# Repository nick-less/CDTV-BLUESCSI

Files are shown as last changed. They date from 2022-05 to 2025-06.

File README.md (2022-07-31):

A Version of the CDTV SCSI Card with an added bluepill SCSI Emulator

Works with https://github.com/erichelgeson/BlueSCSI

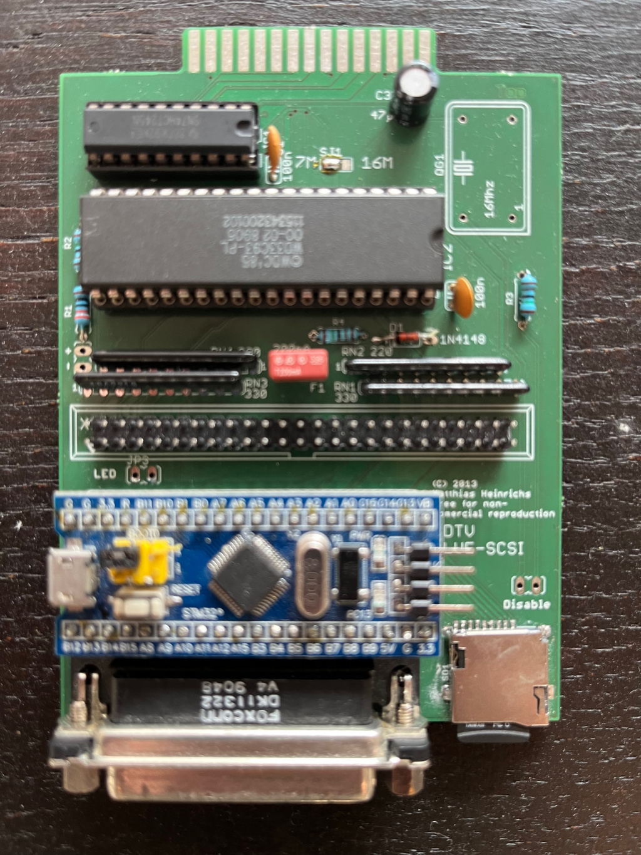
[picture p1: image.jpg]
 

```
Partlist

Part     Value          Package      Library      Position (mil)        Orientation

C1       100n           C025-024X044 rcl          (1318 3336)           R90
C2       100n           C025-024X044 rcl          (2406 2573)           R90
C3       47µ            E2,5-6E      rcl          (2144 3728)           R0
CN1      CDTV-EXPANSION CDTV-SLOT    Amiga        (1535 3964)           R180
D1       1N4148         DO35-7       diode        (2118 2309)           R0
F1       200mA          TE5          fuse         (1472 2144)           R180
IC1      74HC245N       DIL20        74xx-eu      (742 3468)            R180
IC2      WD33C93A       DIP40-6      Amiga        (1274 2824)           R180
JP1                     JP1          jumper       (160 2192)            R180
JP2                     JP1          jumper       (2868 814)            R270
JP3                     JP1          jumper       (528 1488)            R270
QG1      16Mhz          DIL14S       crystal      (2617 3349)           R90
R1       330            0207/7       rcl          (164 2475)            R270
R2       1k             0207/7       rcl          (164 2846)            R90
R3       1k             0207/7       rcl          (2827 2549)           R270
R4       1k             0207/7       rcl          (1712 2336)           R0
RN1      330            SIL10        resistor-sil (2338 2019)           R180
RN2      220            SIL10        resistor-sil (2238 2149)           R0
RN3      330            SIL10        resistor-sil (638 2019)            R0
RN4      220            SIL10        resistor-sil (738 2148)            R180
SD1      TF-HOLDER      TF-PULL      sd-mmc       (2688 272)            R180
SJ1                     SJ_2         jumper       (1697 3367)           R0
U$1                     BLUE_PILL    BluePill     (864 992)             R90
X1       057-050-1      057-050-1    con-panduit  (1488 1746)           R0
X2                      F25H         SparkFun     (1152 304)            R180
```

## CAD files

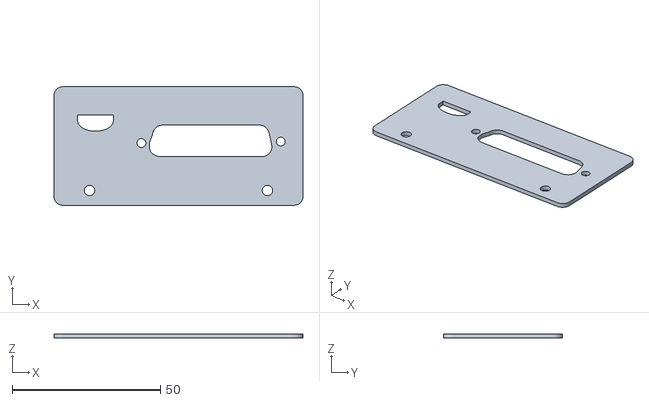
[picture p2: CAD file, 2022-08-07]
backpanel.stl
84.0 x 40.0 x 1.50

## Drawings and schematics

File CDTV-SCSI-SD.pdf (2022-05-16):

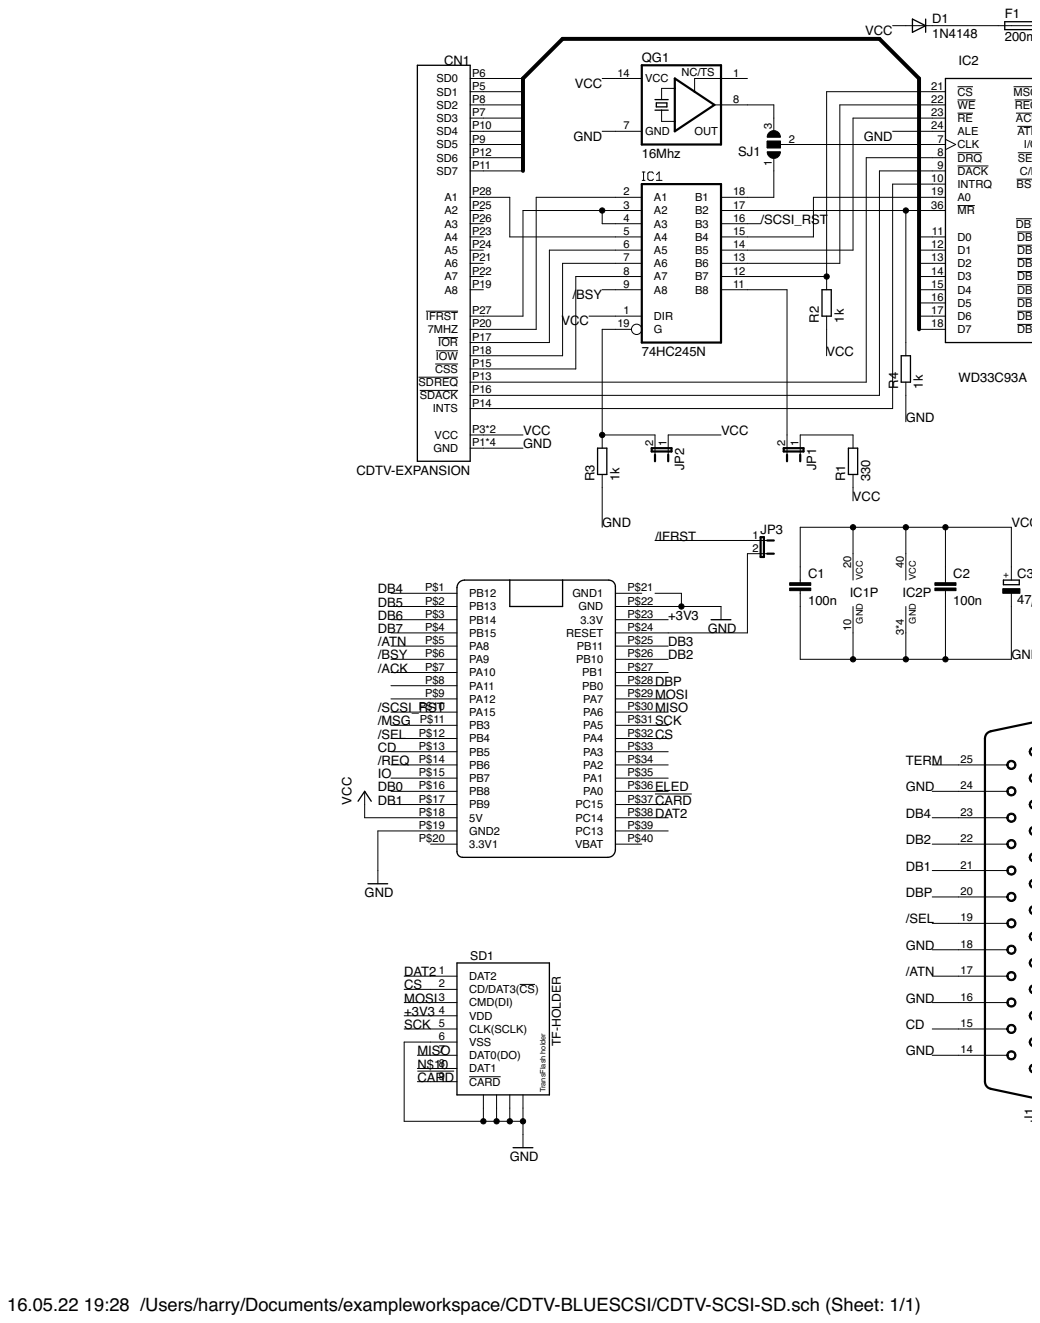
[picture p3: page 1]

16.05.22 19:28 /Users/harry/Documents/exampleworkspace/CDTV-BLUESCSI/CDTV-SCSI-SD.sch (Sheet: 1/1)

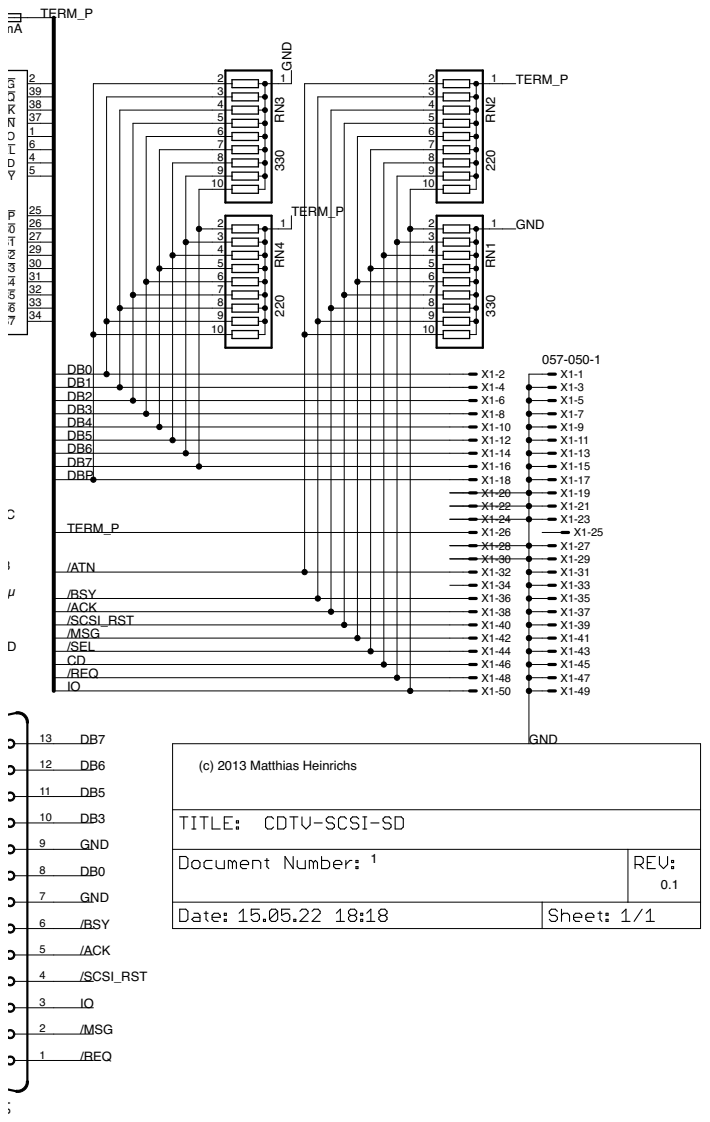
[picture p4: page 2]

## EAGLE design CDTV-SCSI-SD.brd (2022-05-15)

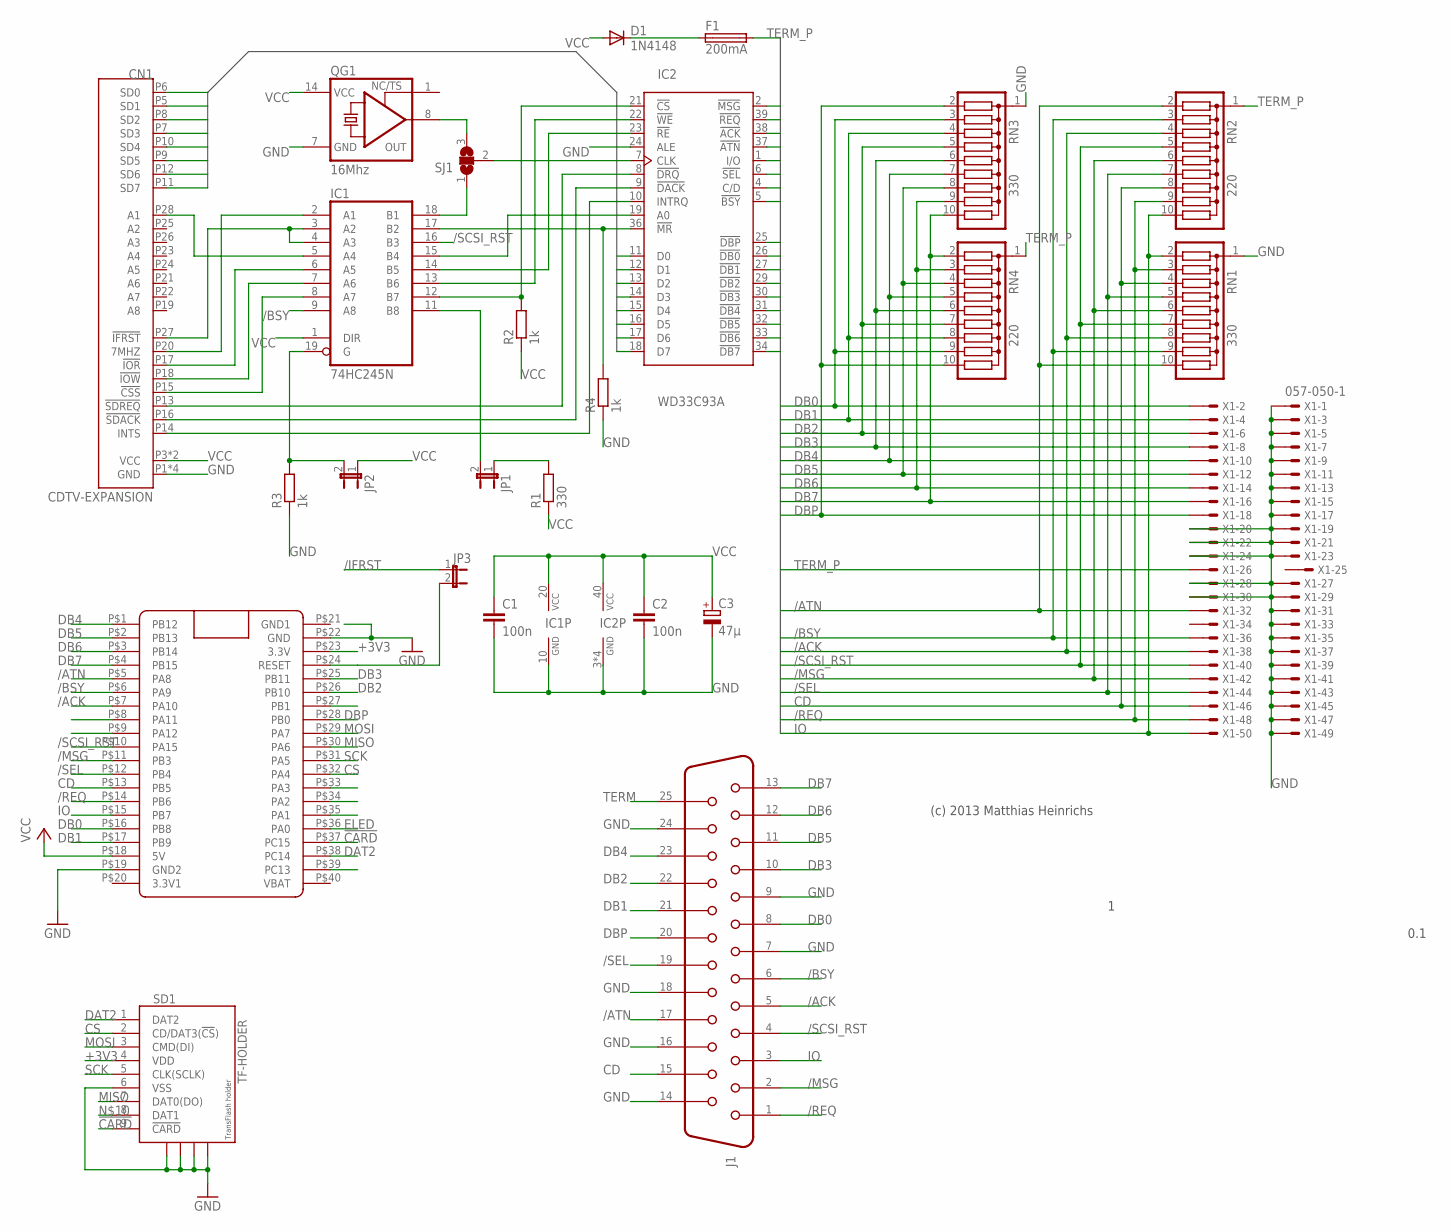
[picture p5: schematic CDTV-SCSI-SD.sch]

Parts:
C1, C2: 100n; C025-024X044
C3: 47µ; E2,5-6E
CN1: CDTV-EXPANSION; CDTV-SLOT
D1: 1N4148; DO35-7
F1: 200mA; TE5
IC1: 74HC245N; DIL20
IC2: WD33C93A; DIP40-6
J1: 61802529321
JP1, JP2, JP3: JP1E; JP1
QG1: 16Mhz; DIL14S
R1: 330; 0207/7
R2, R3, R4: 1k; 0207/7
RN1, RN3: 330; SIL10
RN2, RN4: 220; SIL10
SD1: TF-HOLDER; TF-PULL
SJ1: SJ2W; SJ_2
U$1: BLUE_PILL
X1: 057-050-1

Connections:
7MHZ: CN1.P20 (7MHZ), IC1.2 (A1)
!CARD: SD1.9 (!CARD), U$1.P$37 (PC15)
+3V3: SD1.4 (VDD), U$1.P$23 (3.3V)
/ACK: IC2.38 (!ACK), J1.5, RN1.8, RN2.4, U$1.P$7 (PA10), X1.38
/ATN: IC2.37 (!ATN), J1.17, RN1.10, RN2.2, U$1.P$5 (PA8), X1.32
/BSY: IC1.9 (A8), IC2.5 (!BSY), J1.6, RN1.9, RN2.3, U$1.P$6 (PA9), X1.36
/BSY_B: IC1.11 (B8), JP1.2
/CS: IC1.12 (B7), IC2.21 (!CS), R2.2
/CSS: CN1.P15 (!CSS), IC1.8 (A7)
/ENABLE: IC1.19 (G), JP2.2, R3.2
/IFRST: CN1.P27 (!IFRST), IC1.3 (A2), IC1.4 (A3), JP3.1
/INTS: CN1.P14 (INTS), IC2.10 (INTRQ)
/IOR: CN1.P17 (!IOR), IC1.6 (A5)
/IOW: CN1.P18 (!IOW), IC1.7 (A6)
/MR: IC1.17 (B2), IC2.36 (!MR), R4.2
/MSG: IC2.2 (!MSG), J1.2, RN1.6, RN2.6, U$1.P$11 (PB3), X1.42
/RE: IC1.14 (B5), IC2.23 (!RE)
/REQ: IC2.39 (!REQ), J1.1, RN1.3, RN2.9, U$1.P$14 (PB6), X1.48
/SCSI_RST: IC1.16 (B3), J1.4, RN1.7, RN2.5, U$1.P$10 (PA15), X1.40
/SDACK: CN1.P16 (!SDACK), IC2.9 (!DACK)
/SDREQ: CN1.P13 (!SDREQ), IC2.8 (!DRQ)
/SEL: IC2.6 (!SEL), J1.19, RN1.5, RN2.7, U$1.P$12 (PB4), X1.44
/WE: IC1.13 (B6), IC2.22 (!WE)
A1: CN1.P28 (A1), IC1.5 (A4)
B_A1: IC1.15 (B4), IC2.19 (A0)
CD: IC2.4 (C/D), J1.15, RN1.4, RN2.8, U$1.P$13 (PB5), X1.46
CLK: IC2.7 (CLK), SJ1.2
CLK_7: IC1.18 (B1), SJ1.1
CLK_16M: QG1.8 (OUT), SJ1.3
CS: SD1.2 (CD/DAT3(!CS!)), U$1.P$32 (PA4)
DAT2: SD1.1 (DAT2), U$1.P$38 (PC14)
DB0: IC2.26 (!DB0), J1.8, RN3.3, RN4.9, U$1.P$16 (PB8), X1.2
DB1: IC2.27 (!DB1), J1.21, RN3.4, RN4.8, U$1.P$17 (PB9), X1.4
DB2: IC2.29 (!DB2), J1.22, RN3.5, RN4.7, U$1.P$26 (PB10), X1.6
DB3: IC2.30 (!DB3), J1.10, RN3.6, RN4.6, U$1.P$25 (PB11), X1.8
DB4: IC2.31 (!DB4), J1.23, RN3.7, RN4.5, U$1.P$1 (PB12), X1.10
DB5: IC2.32 (!DB5), J1.11, RN3.8, RN4.4, U$1.P$2 (PB13), X1.12
DB6: IC2.33 (!DB6), J1.12, RN3.9, RN4.3, U$1.P$3 (PB14), X1.14
DB7: IC2.34 (!DB7), J1.13, RN3.10, RN4.2, U$1.P$4 (PB15), X1.16
DBP: IC2.25 (!DBP), J1.20, RN3.2, RN4.10, U$1.P$28 (PB0), X1.18
ELED: U$1.P$36 (PA0)
GND: C1.2, C2.2, C3.-, CN1.P1 (GND), CN1.P2 (GND), CN1.P29 (GND), CN1.P30 (GND), IC1.10 (GND), IC2.3 (GND1), IC2.20 (GND1), IC2.24 (ALE), IC2.28 (GND1), IC2.35 (GND1), J1.7, J1.9, J1.14, J1.16, J1.18, J1.24, QG1.7 (GND), R3.1, R4.1, RN1.1, RN3.1, SD1.6 (VSS), SD1.S1, SD1.S2, SD1.S3, SD1.S4, U$1.P$19 (GND2), U$1.P$22 (GND), X1.1, X1.3, X1.5, X1.7, X1.9, X1.11, X1.13, X1.15, X1.17, X1.19, X1.20, X1.21, X1.22, X1.23, X1.24, X1.27, X1.28, X1.29, X1.30, X1.31, X1.33, X1.35, X1.37, X1.39, X1.41, X1.43, X1.45, X1.47, X1.49
GND1: U$1.P$21 (GND1)
IO: IC2.1 (I/O), J1.3, RN1.2, RN2.10, U$1.P$15 (PB7), X1.50
LED_POW: JP1.1, R1.2
MISO: SD1.7 (DAT0(DO)), U$1.P$30 (PA6)
MOSI: SD1.3 (CMD(DI)), U$1.P$29 (PA7)
unnamed: JP3.2, U$1.P$24 (RESET)
SCK: SD1.5 (CLK(SCLK)), U$1.P$31 (PA5)
SD0: CN1.P6 (SD0), IC2.11 (D0)
SD1: CN1.P5 (SD1), IC2.12 (D1)
SD2: CN1.P8 (SD2), IC2.13 (D2)
SD3: CN1.P7 (SD3), IC2.14 (D3)
SD4: CN1.P10 (SD4), IC2.15 (D4)
SD5: CN1.P9 (SD5), IC2.16 (D5)
SD6: CN1.P12 (SD6), IC2.17 (D6)
SD7: CN1.P11 (SD7), IC2.18 (D7)
TERM: J1.25
TERM_P: F1.2, RN2.1, RN4.1, X1.26
TP_UNFUSED: D1.C, F1.1
VCC: C1.1, C2.1, C3.+, CN1.P3 (VCC), CN1.P4 (VCC), D1.A, IC1.1 (DIR), IC1.20 (VCC), IC2.40 (VCC1), JP2.1, QG1.14 (VCC), R1.1, R2.1, U$1.P$18 (5V)

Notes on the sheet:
0.1
(c) 2013 Matthias Heinrichs

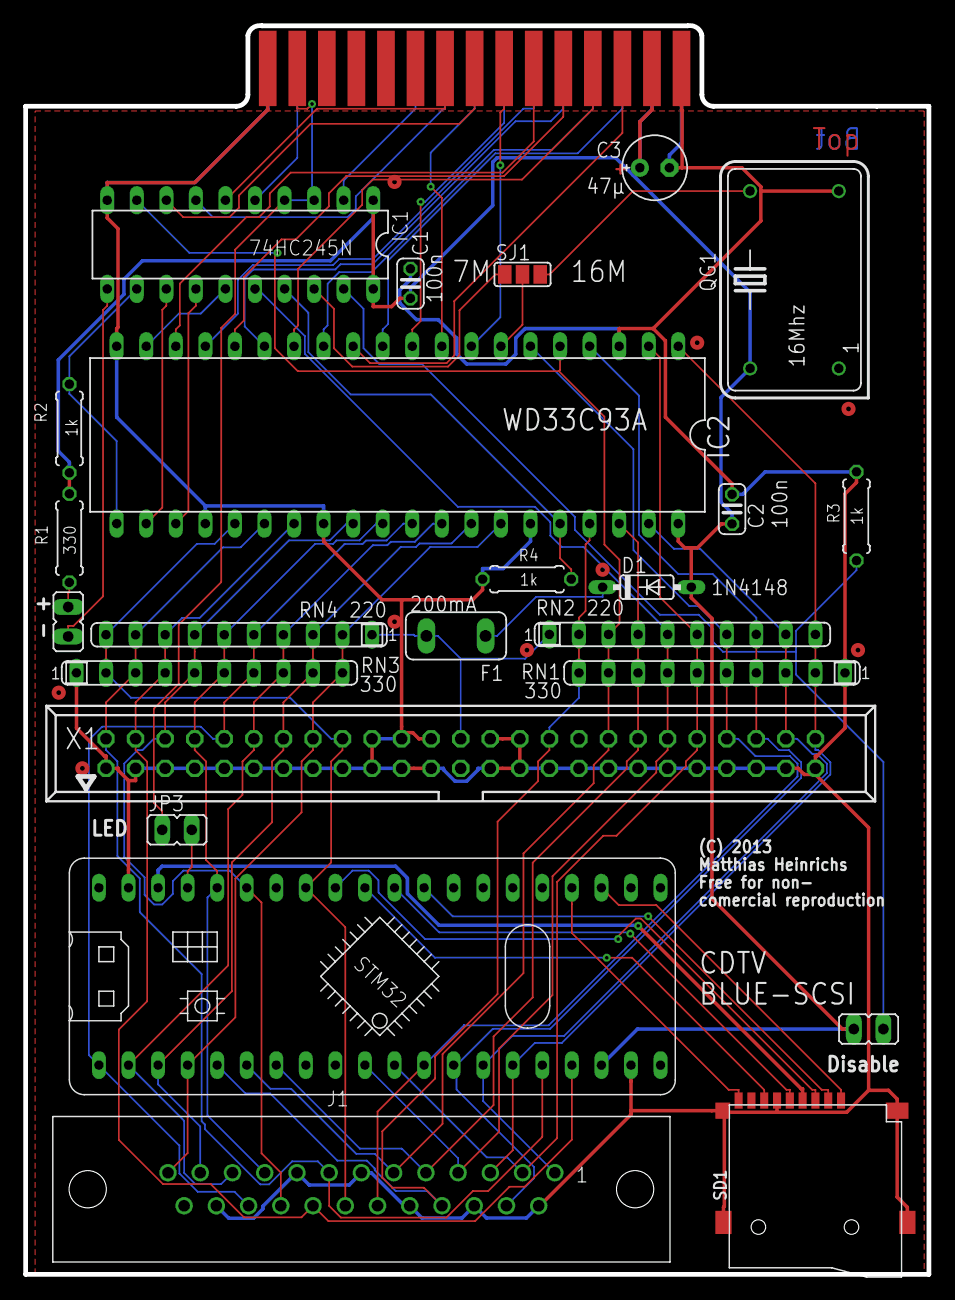
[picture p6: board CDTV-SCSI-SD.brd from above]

Board: 2 copper layers, 77.6 x 107.3 mm, 25 parts (0 on the bottom side), 58 nets.

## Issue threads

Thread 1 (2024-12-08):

Function of the JP3 jumper

LejonD, 2024-12-08:
Hello Nick,

Question what is the function of the JP3 jumper?
The JP2 is for disable/enable
The JP1 is for the LED.

So could you explain.

Lejon

nick-less, 2024-12-10:
JP3 connects /IFRST, which is the buffered /RESET signal from the CDTV to the STM32 reset input. Closing it will reset the STM32 whenever the Amiga is reset.

LejonD, 2024-12-10:
Could you also tell fot the TF-Holder, the card detect is it a open signal when (Micro)SD card is in or a closed signal when (Micro) SD card is in. Closed line is pulled to ground, or line open.
Lejon

nick-less, 2024-12-11:
Well, on my prototype inserting the card pulls it to ground, with no card its floating. Given that, you need to activate the builtin pullups on the stm32. I assume BiueSCSI does exactly that, because it worked out of the box with the prototype.

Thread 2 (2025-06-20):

Image issue?

Piemmeweb, 2025-06-20:
Hi, I built one of it for my CDTV (with dual kickstart 1.3 + 3.1) but it doesn't works. I don't know if it is an image issue or a card problem.
I assembled it totally and not as in the pic of the github page, also I seen on that pic you set up the internal 7 Mhz clock when it should be 16Mhz for the WD33C93A (7Mhz should be for the AM33C93A).
Also I don't know if the CDTV requires a scsi termination even if I didn't found a term jumper on the card.
Please can you tell me how to build the card correctly?
Also , I made an image called HD00_512.hda, in first with dd command, and after installing the workbench 3.1 inside using winuae.  But it doesn't boot, so I did a mistake... where I'm wrong? Can you tell me please how to build a working image? thanks in advance

nick-less, 2025-06-20:
Hi, first I updated the picture to reflect the working prototype. The one in the picture still shows MOSI and MISO flipped, so it’s not exactly the same as the version in this repository.

The 7 MHz clock for the WD33C93A always worked for me, so I never changed it. I had all the parts, except the termination resistors, laying around and didn’t want to wait to put it together. When I later ordered the termination resistors—which are totally needed—I also ordered a clock crystal but never bothered to install it. Technically, you would need termination on both sides, but since the length of the SCSI bus is very short, my version works with only the WD33C93A side terminated. However, adding a second set of termination might improve stability. If you’re cautious about termination, you can add an external terminator using the DB25 connector.

For the disk image, “HD00_512.hda” is okay (disk0, lun0, 512-byte blocks). Did you use HDToolbox to prepare it? Did you try it in UAE? Does it boot in UAE with the same Kickstart version?

Is the SD card formatted using FAT32 or ExtFS? NTFS usually doesn’t work. It’s also probably better to start with an image smaller than 2 GB. There are ways to use bigger images, but for a first test, keep it below 2 GB.

Does the device show up in autoconfig?

What does the LOG.txt on the SD card tell you? When you build the Bluescsi image, you can enable logging, which will write some information to the card, something like:

BlueSCSI <-> SD - https://github.com/erichelgeson/BlueSCSI
VERSION: 1.1-SNAPSHOT-20220627
DEBUG:0 SDFAT_FILE_TYPE:3
SdFat version: 2.0.6
Sd Format: exFAT
SPI speed: 50Mhz
SdFat Max FileName Length: 32
Initialized SD Card - lets go!
Sd MID:9F OID:TI
Sd Name:SD16G
Sd Date:3/2013
Sd Serial:347212878
 - HD20_512-1GB-MacPlus-6+7.hda / 1073741824bytes / 1048576KiB / 1024MiB
 - HD10_512.hda / 2097152000bytes / 2048000KiB / 2000MiB
 - HD00_512.hda / 2097152000bytes / 2048000KiB / 2000MiB
ID:LUN0:
 0: 512:
 1: 512:
 2: 512:
 3:----:
 4:----:
 5:----:
 6:----:
Finished initialization of SCSI Devices - Entering main loop.

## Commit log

2022-05-13 (fix), db25 was male instead of female
    [CDTV-SCSI-SD.brd, CDTV-SCSI-SD.sch]
2022-05-15 (fix), MOSI and SCK were switched
    [CDTV-SCSI-SD.brd, CDTV-SCSI-SD.sch]
2022-05-16 (enhancement), add picture of board
2022-08-07 added a backpanel model
    [backpanel.stl]
2022-08-07 updated backpanel model
    [backpanel.stl]

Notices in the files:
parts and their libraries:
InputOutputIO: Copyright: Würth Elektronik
